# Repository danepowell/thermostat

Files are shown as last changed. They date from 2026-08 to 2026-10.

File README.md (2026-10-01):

<!--
SPDX-FileCopyrightText: 2026 Dane Powell

SPDX-License-Identifier: GPL-3.0-or-later
-->

# ESPHome E-Paper Thermostat

This is an ESPHome touch e-paper thermostat based on the following hardare:

- [XIAO ESP32C6](https://wiki.seeedstudio.com/xiao_esp32c6_getting_started/)
- [Waveshare 2.9in E-Paper Touch HAT](https://www.waveshare.com/2.9inch-Touch-e-Paper-HAT.htm)
- [Pololu U1V11F5 5V regulator](https://www.pololu.com/product/2562)
- 240 mAh 1S LiPo battery

> [!NOTE]
> This is a work in progress and still in a pre-protoype phase. Use at your own risk.

Depends on:

- https://github.com/danepowell/kicad-pololu/

Still in progress:

- Improve battery life (currently only ~5 hours)
- Add a temperature sensor (currently this is more of a remote control than a thermostat, strictly speaking)

The challenge with battery life is the touch sensor and wifi. While the E-Paper display and ESP32 can theoretically go into a deep sleep and consume only a few microamps, this presents two problems:

- We won't receive updates from Home Assistant during this time. One of my biggest grievances with my current IR-based heat pump remote control is that it gets out of sync with changes in Home Assistant, so this is non-negotiable. But maybe we can at least use light sleep and a regular (~15 min) wakeup timer as a compromise.
- The touch display can't be put into any kind of sleep mode without disabling touch updates completely, and it draws quite a bit of power even when idle.

Supposedly the icnt86 touch controller has a low power scan (gesture) wakeup mode that draws only 1-3 mA, which is still more than desired but an order of magnitude less than normal. It could then pulse on INT to wake the ESP32.

Or we could put the icnt86 into deep sleep and poll every ~300 ms. Not actually sure if this would work.

If we ever get to this point, check that our SCL and SDA lines are explicitly put into INPUT_PULLUP on sleep to avoid leakage current.

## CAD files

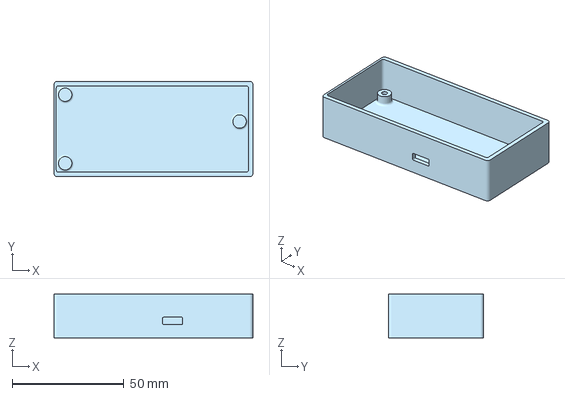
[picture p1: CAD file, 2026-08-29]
case/Thermostat case.3mf
89.1 x 42.7 x 19.7 mm

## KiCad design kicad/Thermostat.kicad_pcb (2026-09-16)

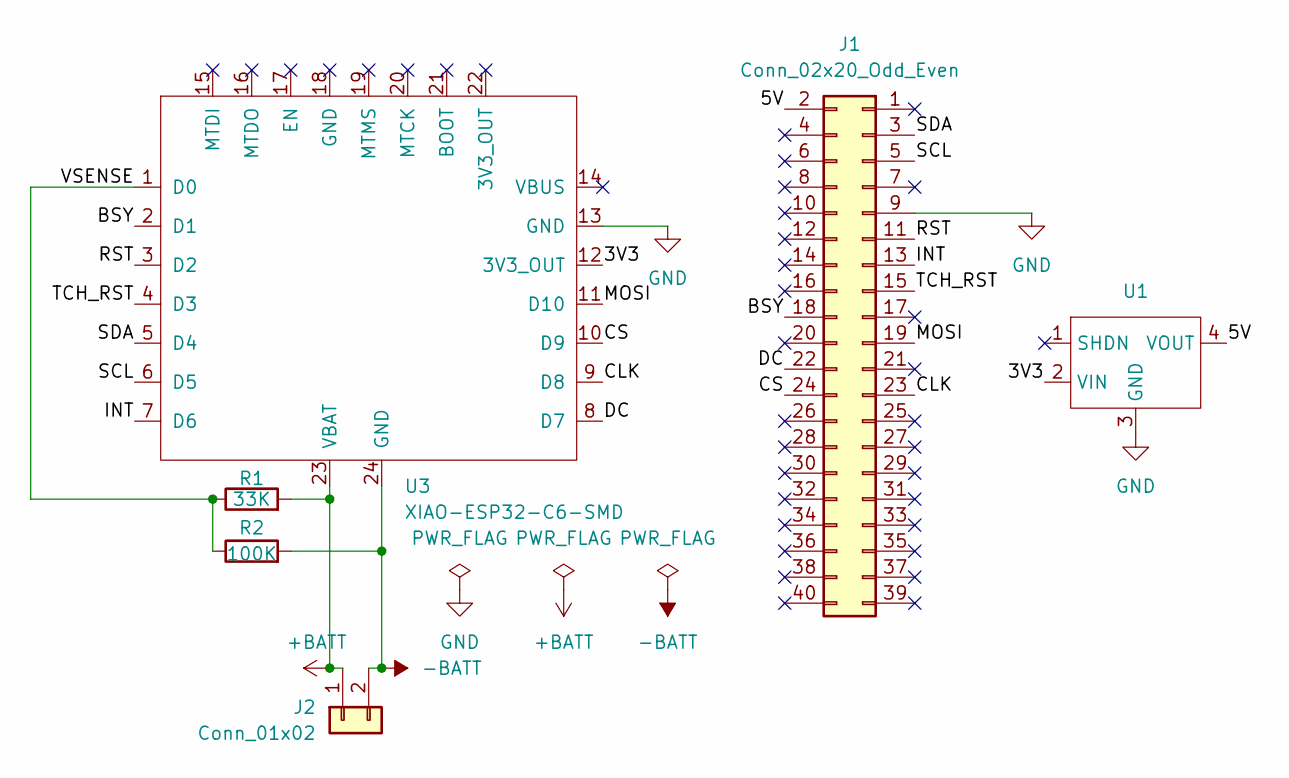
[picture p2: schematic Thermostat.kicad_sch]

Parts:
J1: Conn_02x20_Odd_Even; PinHeader_2x20_P2.54mm_Vertical
J2: Conn_01x02; SolderWire-0.25sqmm_1x02_P4.2mm_D0.65mm_OD1.7mm_Relief
R1: 33K; R_Axial_DIN0207_L6.3mm_D2.5mm_P7.62mm_Horizontal
R2: 100K; R_Axial_DIN0207_L6.3mm_D2.5mm_P7.62mm_Horizontal
U1: U1V11F5
U3: XIAO-ESP32-C6-SMD

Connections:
+BATT: J2.1, R1.2, U3.23 (VBAT)
-BATT: J2.2, R2.2, U3.24 (GND)
/3V3: U1.2 (VIN), U3.12 (3V3_OUT)
/5V: J1.2, U1.4 (VOUT)
/BSY: J1.18, U3.2 (D1)
/CLK: J1.23, U3.9 (D8)
/CS: J1.24, U3.10 (D9)
/DC: J1.22, U3.8 (D7)
/INT: J1.13, U3.7 (D6)
/MOSI: J1.19, U3.11 (D10)
/RST: J1.11, U3.3 (D2)
/SCL: J1.5, U3.6 (D5)
/SDA: J1.3, U3.5 (D4)
/TCH_RST: J1.15, U3.4 (D3)
/VSENSE: R1.1, R2.1, U3.1 (D0)
GND: J1.9, U1.3 (GND), U3.13 (GND)

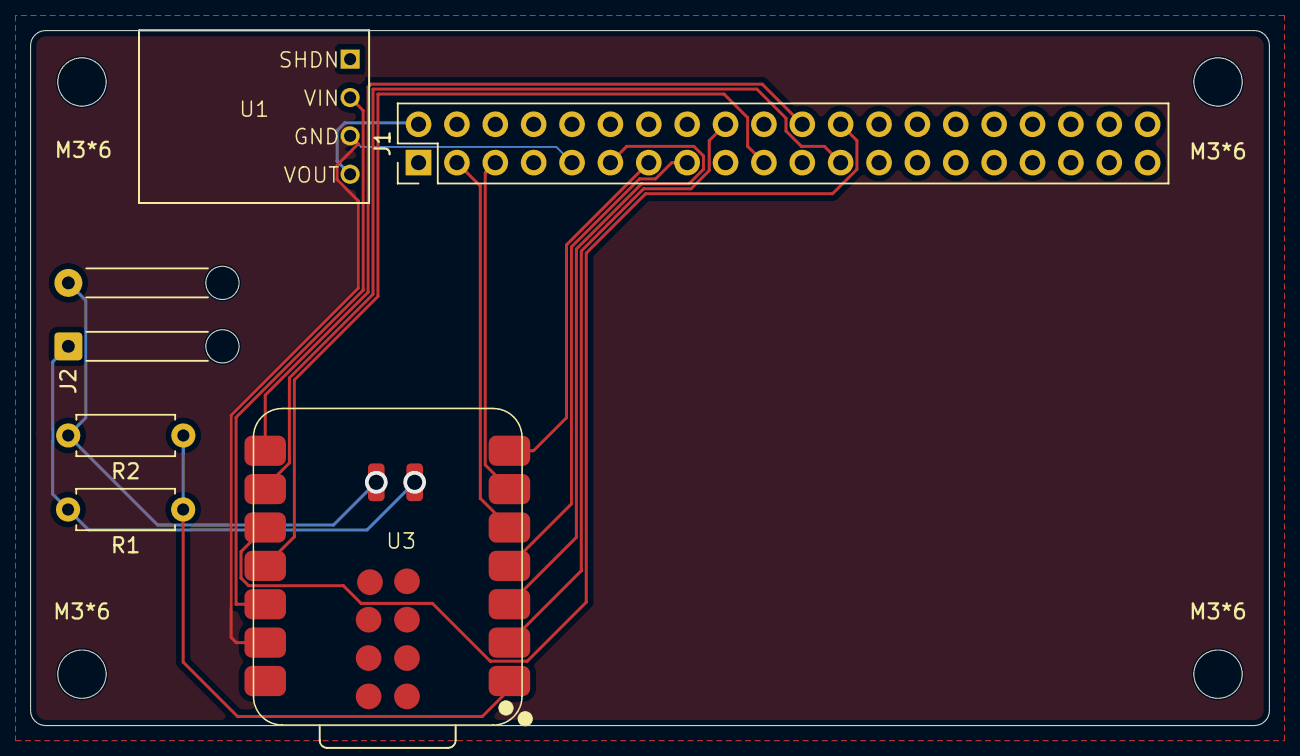
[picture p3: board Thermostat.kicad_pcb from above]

Board: 4 copper layers, 82.0 x 46.0 mm, 10 parts (0 on the bottom side), 16 nets.

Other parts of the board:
M3*6, M3*6#2, M3*6#3, M3*6#4: MountingHole_3.2mm_M3

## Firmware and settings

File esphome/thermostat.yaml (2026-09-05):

esphome:
  name: thermostat
  friendly_name: Thermostat
  includes:
    - button_layout.h

esp32:
  variant: ESP32C6
  framework:
    type: esp-idf

logger:
  level: DEBUG

api:
  encryption:
    key: !secret thermostat__encryption_key
  on_client_connected:
    - component.update: display_waveshare_epaper_1
  on_client_disconnected:
    - component.update: display_waveshare_epaper_1
ota:
  - platform: esphome

wifi:
  ssid: !secret wifi_ssid
  password: !secret wifi_password
  ap:
    ssid: Thermostat Fallback Hotspot
    password: !secret thermostat__ap_password
captive_portal:

# SPI for display (Waveshare Touch E-Paper HAT)
spi:
  clk_pin: GPIO19
  mosi_pin: GPIO18
  id: spi_1

# I2C for touch controller (Waveshare Touch E-Paper HAT)
i2c:
  sda: GPIO22
  scl: GPIO23
  scan: false
  id: bus_a

image:
  - platform: file
    type: BINARY
    file: "mdi:chevron-up"
    id: "plus"
  - platform: file
    type: BINARY
    file: "mdi:chevron-down"
    id: "minus"
  - platform: file
    type: BINARY
    file: "mdi:power"
    id: "off"
  - platform: file
    type: BINARY
    file: "mdi:radiator"
    id: "heat"
  - platform: file
    type: BINARY
    file: "mdi:snowflake"
    id: "cool"
  - platform: file
    type: BINARY
    file: "mdi:fan"
    id: "fan"
  - platform: file
    type: BINARY
    file: "mdi:arrow-right"
    id: "arrow"
  - platform: file
    type: BINARY
    file: "mdi:battery"
    id: "battery_high"
  - platform: file
    type: BINARY
    file: "mdi:battery-70"
    id: "battery_medium"
  - platform: file
    type: BINARY
    file: "mdi:battery-30"
    id: "battery_low"
  - platform: file
    type: BINARY
    file: "mdi:battery-off"
    id: "battery_none"
  - platform: file
    type: BINARY
    file: "mdi:cloud-off-outline"
    id: "disconnected"

font:
  - file: "gfonts://Roboto"
    id: font_lg
    size: 32
  - file: "gfonts://Roboto"
    id: font_md
    size: 22

external_components:
  - source:
      type: git
      url: https://github.com/danepowell/esphome
      ref: 1cbd2aeab411ae8bcecfd5386235272a66adf42d
    components: [ icnt86 ]
  - source:
      type: git
      url: https://github.com/danepowell/esphome
      ref: 14163ecde1aa4aa902bdaf3e60f4bb7eb6864ae1
    components: [ epaper_spi ]

# Use local variables so +/- feels responsive.
globals:
  - id: target_temp_local
    type: int
    initial_value: "72"
  - id: current_temp_local
    type: int
    initial_value: "72"
  - id: hvac_mode
    type: std::string
    initial_value: '"unknown"'

sensor:
  - platform: homeassistant
    id: hp_current_temp
    entity_id: climate.officeheatpump
    attribute: current_temperature
    on_value:
      then:
        - lambda: |-
            id(current_temp_local) = x;
        - component.update: display_waveshare_epaper_1

  - platform: homeassistant
    id: hp_target_temp
    entity_id: climate.officeheatpump
    attribute: temperature
    on_value:
      then:
        - lambda: |-
            id(target_temp_local) = x;
        - component.update: display_waveshare_epaper_1
  # Raw ADC reading from the battery voltage divider.
  - platform: adc
    id: adc_batt_raw
    pin: GPIO0
    attenuation: 12db
    update_interval: 5min
    internal: true
  # Convert raw ADC reading to battery voltage.
  - platform: copy
    source_id: adc_batt_raw
    id: battery_voltage
    name: "Battery Voltage"
    unit_of_measurement: "V"
    device_class: voltage
    state_class: measurement
    accuracy_decimals: 2
    filters:
      - multiply: 1.33 # NOTE: Calibrate this multiplier for your specific voltage divider.
  # Convert battery voltage to a percentage using a non-linear curve for LiPo batteries.
  - platform: copy
    source_id: battery_voltage
    id: battery_percent
    name: "Battery Level"
    unit_of_measurement: "%"
    device_class: battery
    state_class: measurement
    accuracy_decimals: 0
    filters:
      # This curve maps voltage to percentage. Adjust for your specific battery.
      - calibrate_linear:
          - 4.18 -> 100
          - 4.00 -> 85
          - 3.85 -> 60
          - 3.80 -> 50
          - 3.70 -> 25
          - 3.50 -> 5
          - 3.30 -> 0
      # Clamp values to the 0-100% range and apply a moving average to smooth out readings.
      - clamp:
          min_value: 0
          max_value: 100
      - sliding_window_moving_average:
          window_size: 4
          send_every: 1
    on_value_range:
      - below: 25.1
        then:
          # A near-zero voltage means no battery is attached (divider pulled to
          # ground) and we're running on USB, so don't sleep.
          - if:
              condition:
                lambda: 'return id(battery_voltage).state > 2.5;'
              then:
                - logger.log: "Battery critical, entering deep sleep."
                - deep_sleep.enter: battery_saver_sleep
              else:
                - logger.log: "No battery detected, staying awake on USB power."
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

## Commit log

2026-08-28 assign footprint
    [Thermostat.kicad_sch]
2026-08-29 add case
    [Thermostat case.3mf]
2026-08-29 specify battery
2026-08-29 pcb in progress
    [Thermostat.kicad_pcb, Thermostat.kicad_sch]
2026-08-29 hat header position
    [Thermostat.kicad_pcb]
2026-08-29 PCB physical layout
    [Thermostat.kicad_pcb, Thermostat.kicad_sch]
2026-08-30 add battery connector
    [Thermostat.kicad_pcb, Thermostat.kicad_sch]
2026-08-31 working on pcb
    [Thermostat.kicad_pcb, Thermostat.kicad_sch]
2026-09-12 traces complete
    [Thermostat.kicad_pcb]
2026-09-16 resolving issues
    [Thermostat.kicad_pcb]
2026-09-16 final pcb
    [Thermostat-B_Mask.gbs, Thermostat-B_Paste.gbp, Thermostat-B_Silkscreen.gbo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]
